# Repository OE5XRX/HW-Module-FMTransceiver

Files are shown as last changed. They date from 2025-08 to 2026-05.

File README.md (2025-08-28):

# HW-Module-Template

## Description

This repository is a template for hardware modules using KiCad, designed for clean, maintainable development with CI/CD pipelines generating and publishing production data automatically.

## Features
* Structured KiCad project (schematic, PCB)
* Clean repository: no production data stored
* GitHub Actions CI/CD pipeline:
  * Generates Gerber, BOM, and assembly files
  * Uploads artifacts to GitHub Releases
* Open Hardware license ready (CERN-OHL-S)

## Repository Structure

```
HW-Module-Template/
├── .github/workflows/     # CI/CD pipeline scripts
├── doc/                   # Documentation exports
├── symbols/               # Local symbol library (if needed)
├── footprints/            # Local footprint library (if needed)
├── 3d-models/             # STEP/WRL files (optional)
├── main.kicad_pro         # KiCad main project file
├── main.kicad_sch         # KiCad main schematic file
├── main.kicad_pcb         # KiCad main pcb file
├── *.kicad_sch            # other KiCad schematic files
├── LICENSE
└── README.md
```

## Usage
1. Click “Use this template” on GitHub.
2. Clone your repository locally and open in KiCad.
3. fix the missing names in the readme and add documentation in the `doc/index.md` file.
4. Work on your schematic and PCB as usual (create a new project (main-file must be called `main.kicad_*`) or copy a new one into the folder structure).
5. Push your changes.
6. CI/CD will automatically generate production files.
7. If there is a release defined, CI/CD will create a documentation on the main webpage.

## License

This project is licensed under [CERN-OHL-S-2.0](https://choosealicense.com/licenses/cern-ohl-s-2.0/).

## Badges

<br>
<br>
<br>
<br>
<br>

## Contact

OE5XRX Amateur Radio Club<br>
🌐 https://oe5xrx.org<br>
✉️ info@oe5xrx.org<br>

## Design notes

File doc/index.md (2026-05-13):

---
title: FM Transceiver
nav_order: 5
parent: Hardware
description: FM-Schmalband-Transceiver für 2 m (VHF) oder 70 cm (UHF) auf Basis SA818, mit STM32U5 als USB-Bridge — erscheint dem CM4 als USB-Audio-Class-2 + CDC-ACM-Verbund.
---

# FM Transceiver PCB

<table>
  <tr><th>Top</th><th>Bottom</th></tr>
  <tr>
    <td>top</td>
    <td>bottom</td>
  </tr>
</table>

## Übersicht

FM-Schmalband-Transceiver auf Basis des **SA818**-Moduls für die Amateurfunkbänder **2 m (144 – 174 MHz)** *oder* **70 cm (400 – 480 MHz)**. Bestückbar in beiden Varianten — abhängig vom verlöteten SA818-Chip (`SA818V` für VHF / `SA818U` für UHF) und dem dazu passenden Mini-Circuits-Tiefpassfilter (`LFCN-180` für VHF / `LFCN-490` für UHF; identischer FV1206-Footprint).

Zwischen SA818 und CM4 sitzt ein **STM32U575** Mikrocontroller. Er stellt sich am USB als **Composite Device** vor und sieht für das CM4-Linux aus wie:

- **UAC2** (USB Audio Class 2) — TX-Audio strömt vom CM4 als Audio-Sink in den STM32-DAC und von dort als analoges Signal zum SA818-Mic-Input. RX-Audio läuft umgekehrt: SA818-AF_OUT → STM32-ADC → über UAC2 als Audio-Source zurück ans CM4.
- **CDC ACM** (Virtual COM Port) — PTT, Squelch-Read, Frequenz, Power-Level usw. werden vom CM4 als ASCII-Kommandos über `/dev/ttyACM*` gesetzt.
- **DFU** (Device Firmware Upgrade) — STM32-Firmware kann über USB neu geflasht werden, ohne SWD-Adapter und ohne BOOT0-Hardware-Jumper.

Das Modul belegt einen der vier Slots auf dem [BusBoard](../HW-Module-BusBoard/). Die Kommunikation zum CM4 läuft **ausschließlich über USB** (USB-Pair am Bus-Stecker, durch den FE1.1s-Hub auf dem BusBoard); I²C, UART und GPIO-Pins des Bus-Steckers sind NICHT genutzt.

## Block-Diagramm

```mermaid
flowchart LR
    CM4["CM4<br/>(via BusBoard FE1.1s)"]
    CM4 <-->|"USB 2.0<br/>(UAC2 + CDC + DFU)"| ESD["USBLC6-2SC6<br/>ESD"]
    ESD <--> STM32["STM32U575CITx"]

    STM32 -->|"UART RX/TX<br/>AT-Kommandos"| SA["SA818V/U"]
    STM32 -->|"DAC (TX-Audio)"| MICF["DAC→MIC_IN<br/>Filter"]
    MICF --> SA
    SA -->|"AF_OUT (RX-Audio)"| AFF["AF_OUT→ADC<br/>Filter"]
    AFF -->|"ADC"| STM32
    STM32 -->|"GPIO1: PTT"| PDR["Pin-Driver<br/>(MOSFET/NPN)"]
    STM32 -->|"GPIO2: PD"| PDR
    STM32 -->|"GPIO3: H/L"| PDR
    PDR --> SA
    SA -->|"SQUELCH"| PDR
    PDR -->|"GPIO4"| STM32
    SA -->|"RF-Out"| LPF["LPF FL101<br/>(LFCN-180 = 2m,<br/>LFCN-490 = 70cm)"]
    LPF --> ANT(["Antenne<br/>SMA edge"])

    STM32 -.->|"I²C intern"| EEP["CAT24C32<br/>4 KByte EEPROM"]
```

## Band-Varianten

Die Platine ist für beide Amateurfunk-Bänder ausgelegt; bestückungsabhängig:

| Variante | SA818-Chip | LPF-Bestückung (FL101) | Band |
| --- | --- | --- | ---- |
| **2 m / VHF** | `SA818V` | `LFCN-180` | 144 – 174 MHz |
| **70 cm / UHF** | `SA818U` | `LFCN-490` | 400 – 480 MHz |

Es gibt nur **einen einzigen Filter-Footprint** (FL101 — Mini-Circuits FV1206) auf der Platine. Je nach SA818-Bestückung wird das passende LFCN-Bauteil eingelötet.

⚠️ **Wichtig**: SA818-Chip und LPF-Bestückung müssen zueinander passen. Ein falsch bestückter Filter unterdrückt entweder das Nutzband oder lässt zu viele Oberwellen durch → Empfangsperformance schlecht und/oder Verstoß gegen Spektrumvorschriften.

## Steckverbinder

| Bezeichner | Typ | Funktion |
| --- | --- | --- |
| **J101** | Board-Edge SMA | Antennenanschluss (50 Ω) |
| **J201** | 10-Pin 2.54 mm Stiftleiste 2×5 horizontal (right-angle) | STM32-Programming- und Debug-Header (SWD-Pin-Belegung) |
| **J202** | 20-Pin (Hirose **PCN10C-20S-2.54DS** — weibliche Buchse, paart mit dem PCN10-20P-Stift-Header auf dem BusBoard) | Bus-Stecker zum [BusBoard](../HW-Module-BusBoard/) |
| **JP201** | 2× Lötpad | EEPROM-Write-Protect-Brücke (siehe „EEPROM" unten) |

### Bus-Stecker J202 (FM-Slot-Sicht)

Das FM-Modul ist ein Device-Slot-Konsument. Power-Belegung identisch zu allen anderen Slots; nur USB ist aktiv, alle anderen Slot-Signal-Pins (`a7`–`a9`, `b7`–`b9`) sind NC.

| Pin | Net | Pin | Net |
|----:|-----|----:|-----|
| a1  | +12V | b1  | +12V |
| a2  | +12V | b2  | +12V |
| a3  | GND  | b3  | GND  |
| a4  | +5V  | b4  | +5V  |
| a5  | +5V  | b5  | +5V  |
| a6  | USB D+ | b6 | USB D− |
| a7  | NC | b7  | NC |
| a8  | NC | b8  | NC |
| a9  | NC | b9  | NC |
| a10 | GND  | b10 | GND  |

Hinweis: Pin-Numerierung am FM-Modul ist **gespiegelt** ggü. dem BusBoard-Slot (FM `a1` ↔ BusBoard `a10` usw.) — physikalisch passt's. Kanonische Bus-Pinbelegung siehe [BusBoard](../HW-Module-BusBoard/#pin-belegung-20-pin-identisch-auf-allen-konnektoren).

### STM32 SWD-Header J201

10-Pin 2.54-mm-Stiftleiste (2×5, right-angle/horizontal). Pin-Belegung folgt der SWD-Konvention, der Stecker selbst ist aber **kein** Cortex-Debug-1.27-mm-Standard — Adapter-Kabel für 2.54 mm benötigt, oder Jumper-Litzen direkt auf die einzelnen Pins.

| Pin | Signal | Pin | Signal |
|----:|---|----:|---|
| 1 | +3V3 | 2 | SWDIO |
| 3 | GND | 4 | SWCLK |
| 5 | GND | 6 | NC |
| 7 | NC | 8 | NC |
| 9 | GND | 10 | nRESET |

**Pin-1-Lage im Silkscreen ist auf der aktuellen Revision NICHT markiert** ([Issue #13](https://github.com/OE5XRX/HW-Module-FMTransceiver/issues/13)) — Schaltplan zur Hand nehmen oder die Pin-1-Markierung vom Programmer-Kabel mit einem Multimeter gegen `+3V3` verifizieren.

## STM32 ↔ SA818 — Steuersignal-Mapping

Die STM32-GPIOs steuern das SA818 über Level-Shifter (MOSFET / NPN — `pin_driver` und `pin_driver_npn` Sub-Sheets):

| Funktion | Schaltplan-Label | STM32-Pin (LQFP-48) | SA818-Pin | Richtung |
| --- | --- | --- | --- | --- |
| **PTT** (Push-to-Talk) | `GPIO1` | `PB2` (Pin 20) | `~PTT` (Pin 5) | STM32 → SA818 |
| **POWER_DOWN** (Modul ein/aus) | `GPIO2` | `PB1` (Pin 19) | `~PD` (Pin 6) | STM32 → SA818 |
| **H_L_Power** (Sendeleistung high/low) | `GPIO3` | `PB10` (Pin 21) | `H/L` (Pin 7) | STM32 → SA818 |
| **SQUELCH** (Squelch-Open-Indikator) | `GPIO4` | `PB0` (Pin 18) | `~SQ` (Pin 1) | SA818 → STM32 |

Zusätzlich UART auf STM32 USART_TX/USART_RX ↔ SA818 für AT-Kommandos (Frequenz setzen, Modulation, CTCSS, etc. — siehe SA818-Datenblatt).

## Firmware-Rolle (STM32U575)

Die STM32-Firmware (Quelle: [`FW-RemoteStation`](https://github.com/OE5XRX/FW-RemoteStation)) macht aus dem FM-Modul ein selbst beschreibendes USB-Gerät am CM4:

| USB-Klasse | Zweck | CM4-Sicht |
| --- | ----- | --- |
| **UAC2** | Audio-Class 2 für TX- und RX-Audio | Sound-Karte: aufnehmen vom Modul (RX-Audio) und abspielen zum Modul (TX-Audio) per ALSA/PipeWire. |
| **CDC ACM** | Kontroll-Pfad | `/dev/ttyACM*` — ASCII-Kommandos für PTT, Squelch-Read, Frequenz, Power-Level. |
| **DFU** | Firmware-Update | `dfu-util` kann die STM32-FW über USB neu schreiben — **kein BOOT0-Pin-Eingriff nötig**, die laufende Firmware switcht über CDC-Kommando in den DFU-Mode. |

Audio läuft vollständig analog zwischen SA818 und STM32 (DAC/ADC im STM32) — keine Echtzeit-Anforderungen am CM4-Linux nötig, Audio wird als regulärer USB-Audio-Stream behandelt.

## Auf der Platine verbaute Komponenten

| Bauteil | Funktion |
| --- | --- |
| **SA818V / SA818U** (U101) | FM-Schmalband-Transceiver-Modul (1 W TX-Leistung). Bestückung je nach Band. |
| **STM32U575CITx** (U201) | Cortex-M33 USB-Bridge. UAC2 + CDC + DFU Composite Device. |
| **TLV73333PQDBVRQ1** (U203) | Automotive-grade (-Q1) 3.3 V LDO — Versorgung für STM32 + Peripherie. |
| **USBLC6-2SC6** (U204) | USB-ESD-Schutz auf den D±-Leitungen vor STM32. |
| **CAT24C32** (U202) | 32 Kbit (4 KByte) I²C EEPROM. WP-Pin über `JP201`-Lötbrücke konfigurierbar. |
| **LMR51430** (U801) | Buck-Konverter 12 V → 5 V für die SA818-Versorgung. |
| **LFCN-180** *oder* **LFCN-490** (FL101) | Mini-Circuits Tiefpass im Antennen-Pfad (Oberwellen-Unterdrückung). Eines der beiden wird in den FV1206-Footprint bestückt — `LFCN-180` für 2 m, `LFCN-490` für 70 cm. |
| **8 MHz Crystal** | Taktquelle für den STM32U575 (Backup zum HSI). |
| **Pin Driver** (pin_driver / pin_driver_npn Sub-Sheets) | MOSFET- und NPN-Level-Shifter zwischen STM32-3.3-V-GPIOs und SA818. |

## EEPROM (CAT24C32)

4-KByte-EEPROM am internen I²C-Bus des STM32 (separate I²C-Lines `I2C_SCL_MEM`/`I2C_SDA_MEM` von Pin 45/46 — also nicht über den Bus zum CM4 erreichbar). **Vorgesehen für Modul-Konfiguration** (Seriennummer, Kalibrierdaten, gespeicherte Frequenzlisten o.ä.). **Aktuell noch leer** — Firmware definiert das Schema noch.

**Write-Protect** über `JP201` (zwei Lötpads, KEIN Pin-Header):

| JP201 | Verhalten |
| ----- | --- |
| **offen** (Default ab JLCPCB) | EEPROM beschreibbar — STM32 kann CAT24C32 lesen UND schreiben. |
| **gebrückt** (Lötzinn-Brücke) | EEPROM schreibgeschützt (CAT24C32 Pin 7 / WP = high). Nur Lesen möglich. |

In der Endmontage (Produktivbetrieb) ist es empfehlenswert die Brücke zu setzen, damit kein Firmware-Bug versehentlich Kalibrierdaten überschreibt.

## Versorgung

| Rail | Quelle | Verbrauch |
| ---- | --- | --- |
| +12V | Bus-Stecker (vom [PowerBoard](../HW-Module-PowerBoard/)) | < 1 A (SA818 TX-Spitze) |
| +5V  | Lokaler LMR51430 Buck aus +12V | für SA818 |
| +3V3 | Lokaler TLV73333-Q1 LDO aus +5V | für STM32, EEPROM, Pin-Driver-Logik |

Hinweis: das Modul nutzt sowohl die +12V- *als auch* die +5V-Schiene vom Bus — die +5V vom Bus speist die USB-Interface-Schaltung (USBLC6), während die SA818-Versorgung lokal aus den +12V gezogen wird (saubere Trennung von Audio/Digital und HF/Switching-Noise).

## Bestückung

- **SA818** und passender **LFCN-Filter** müssen zusammenpassen — siehe Band-Varianten-Tabelle oben. Bei JLCPCB-Order entsprechende Variant-Auswahl im KiBot-Setup.
- **`JP201`-Lötbrücke** wird ab Werk **offen** geliefert (EEPROM beschreibbar zur Initialkonfiguration). Brücke kann nach Konfiguration mit Lötzinn geschlossen werden.
- Antenne: **Niemals senden ohne Antenne oder 50-Ω-Dummy-Last** am SMA — das SA818 verträgt offene/kurzgeschlossene Antennen-Ports nicht und kann beschädigt werden.

## Bringup

Nach Bestückung (mit Bus + CM4 verbunden):

1. **Power-Sanity:** Modul in Slot stecken, +12 V anlegen, am Bus-Stecker `+5V`-Pin gegen GND messen → 5.00 ± 0.05 V (LMR51430-Output). `+3V3` (z.B. am SWD-Header J201 Pin 1 vs Pin 3) muss 3.30 ± 0.05 V zeigen.
2. **STM32-Boot:** kurze Latenz nach Power-Up sollte am USB ein Composite Device erscheinen (`lsusb -v` am CM4). Drei USB-Interfaces sind erwartet: UAC2 (Audio), CDC ACM (Serial), DFU-Runtime.
3. **Soundkarten-Check:** `aplay -L` / `arecord -L` am CM4 → die FM-Module-UAC2-Soundkarte muss in der Liste sein.
4. **CDC-Konsole:** `screen /dev/ttyACM0 115200` (oder welche Nummer auch immer) — Firmware-spezifisches Prompt/Echo erwartet.
5. **SA818-Smoke:** über CDC-Kommando Frequenz setzen, dann mit Funkscanner / SDR auf der eingestellten Frequenz Trägeraussendung kurz testen (5-Sek-Burst max, **mit Antenne!**).
6. **Firmware-Update-Pfad:** über CDC-Kommando in DFU schalten, mit `dfu-util -l` muss das Modul auftauchen — bestätigt dass auch Firmware-Updates über reines USB möglich sind, ohne SWD-Programmer.

## Verwandte Module

- [BusBoard](../HW-Module-BusBoard/) — stellt USB-Anbindung über FE1.1s-Hub bereit.
- [PowerBoard](../HW-Module-PowerBoard/) — speist +12 V / +5 V am Bus.
- [CM4 Carrier](../HW-Module-CM4Carrier/) — USB-Host und Software-Endpoint für UAC2/CDC/DFU.
- [`FW-RemoteStation`](https://github.com/OE5XRX/FW-RemoteStation) — STM32-Firmware-Quellcode.

## Daten

- [Schaltplan]({{ site.data.project.name }}-schematic.pdf)
- [BOM]({{ site.data.project.name }}-bom.html)
- [iBOM]({{ site.data.project.name }}-ibom.html)
- [JLCPCB fabrication & stencil](JLCPCB/{{ site.data.project.name }}-_JLCPCB_compress.zip)
- [JLCPCB Bom](JLCPCB/{{ site.data.project.name }}_bom_jlc.csv)
- [JLCPCB Pick&Place](JLCPCB/{{ site.data.project.name }}_cpl_jlc.csv)

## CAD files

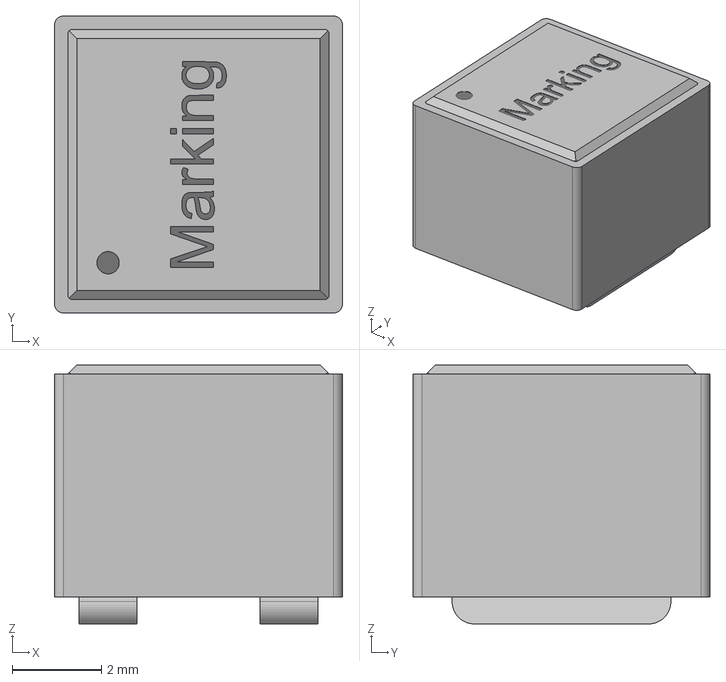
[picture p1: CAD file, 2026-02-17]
3d-models/WE-XHMI-6060.step
6.45 x 6.65 x 5.80 mm

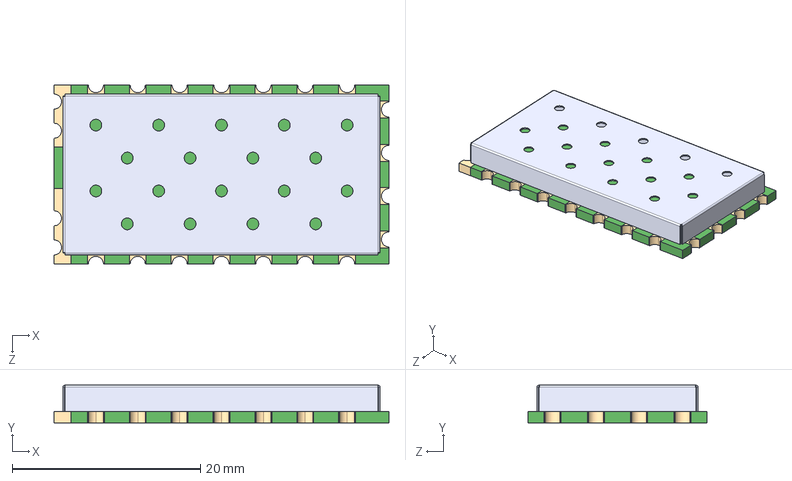
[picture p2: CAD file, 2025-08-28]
3d-models/DRA818.step
35.6 x 4.00 x 19.0 mm

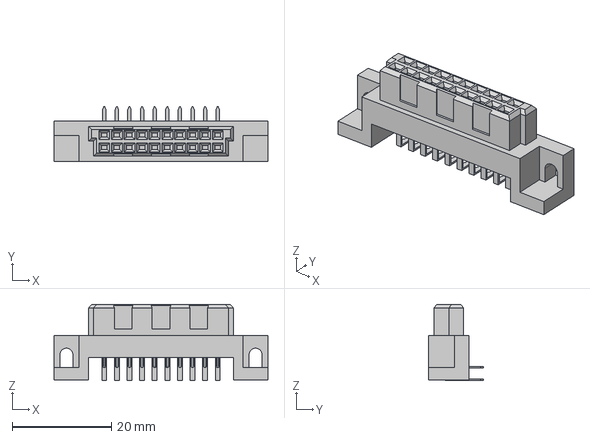
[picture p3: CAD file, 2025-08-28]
3d-models/PCN10C-20S-2.54DS.stp
43.1 x 11.0 x 15.3 mm

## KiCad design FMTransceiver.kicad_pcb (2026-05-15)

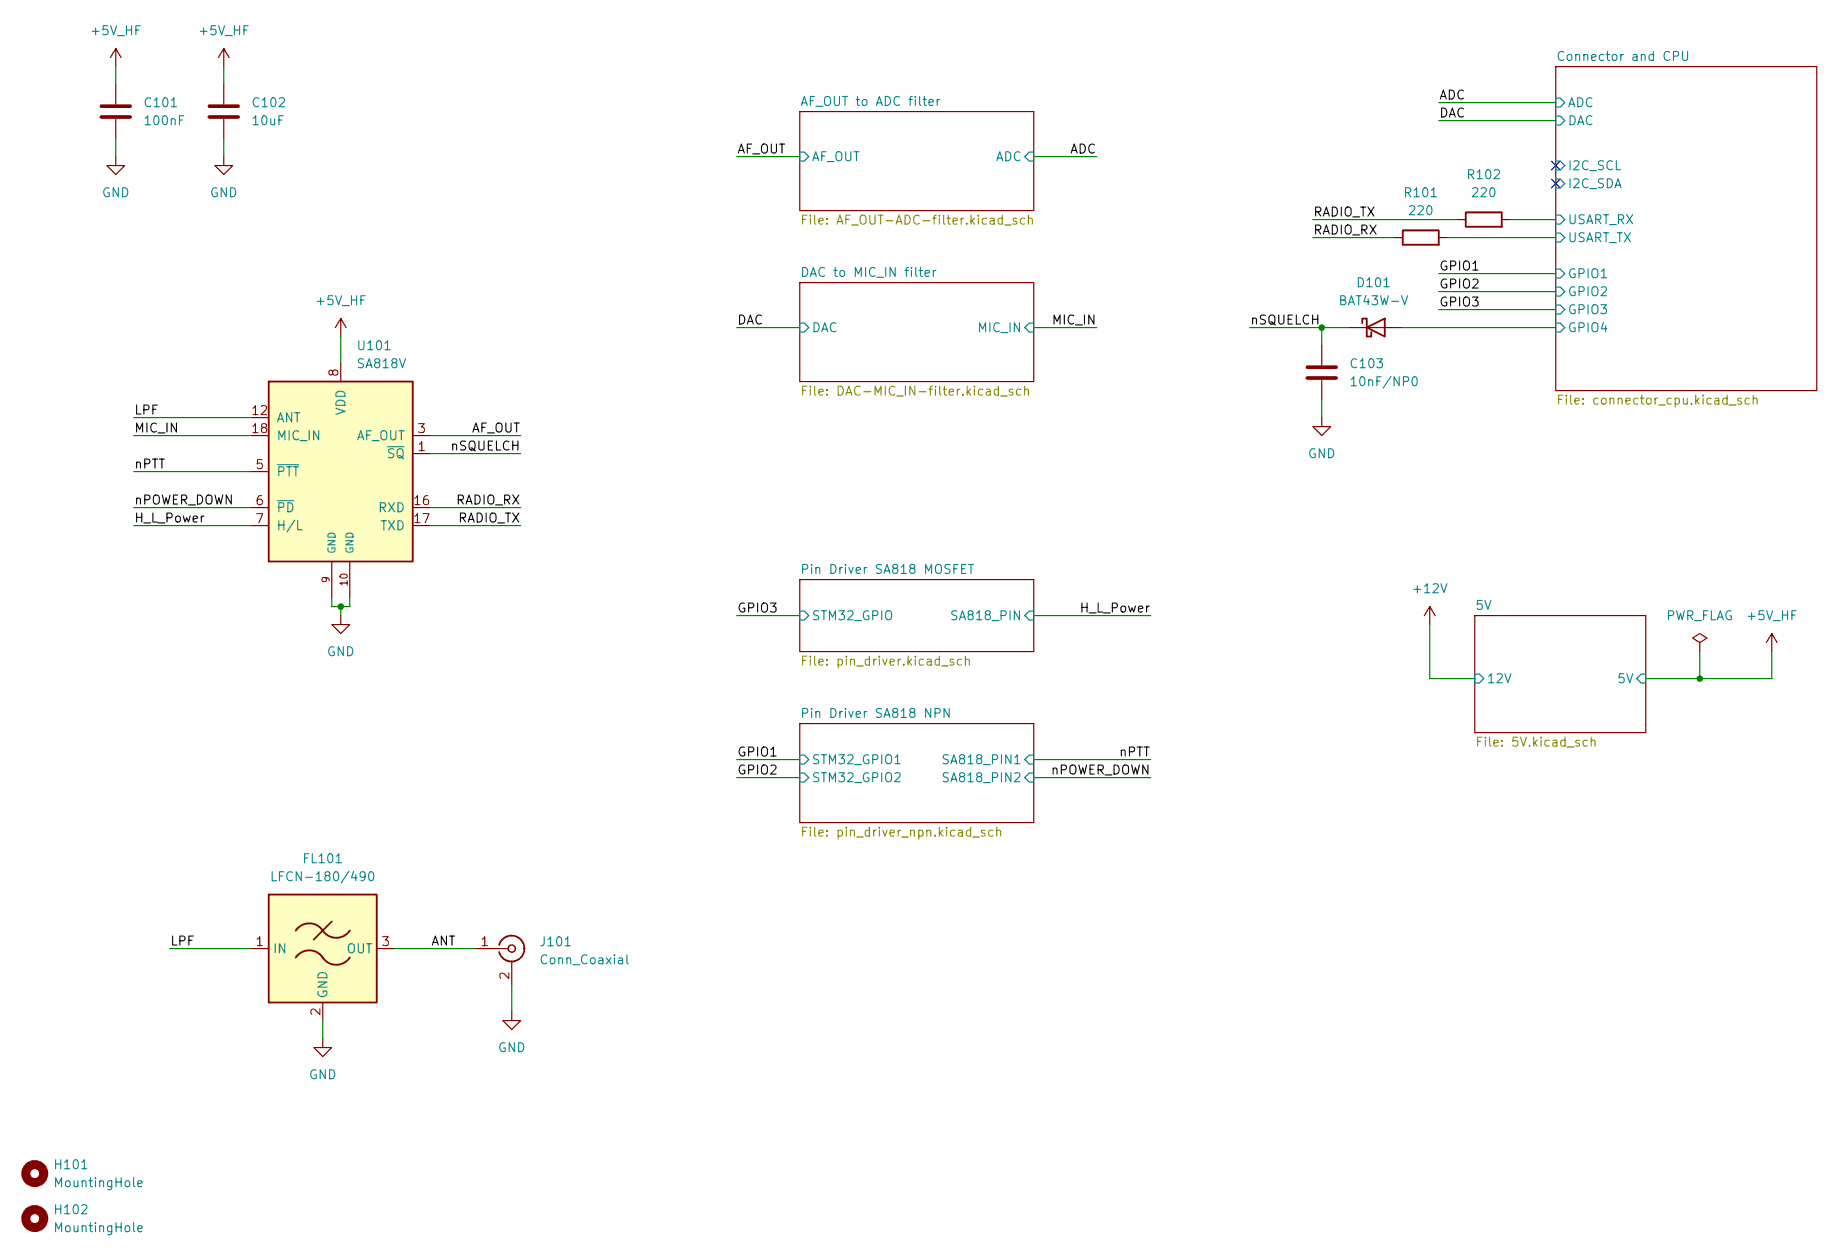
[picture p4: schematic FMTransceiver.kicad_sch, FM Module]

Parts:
C101: 100nF; C_0805_2012Metric; LCSC C28233
C102: 10uF; C_0805_2012Metric; MOUSER 963-EMK212BJ106KG-T
C103: 10nF/NP0; C_0805_2012Metric; MOUSER 81-GRM2165C2A103JA1D
D101: BAT43W-V; D_SOD-123; MOUSER 78-BAT43W-G3-08
FL101: LFCN-180/490; Filter_Mini-Circuits_FV1206; MOUSER 139-LFCN-180,139-LFCN-490
H101, H102: MountingHole; MountingHole_3.2mm_M3
J101: Conn_Coaxial; SMA_Amphenol_132289_EdgeMount; MOUSER 530-142-0701-801
R101, R102: 220; R_0805_2012Metric; MOUSER 667-ERA-6AEB221V
U101: SA818V; DRA818; LCSC C3001504

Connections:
+5V_HF: C101.2, C102.2, U101.8 (VDD); also elsewhere on the board
/AF_OUT: U101.3 (AF_OUT); also elsewhere on the board
/ANT: FL101.3 (OUT), J101.1 (In)
/Connector and CPU/GPIO4: D101.2 (A); also elsewhere on the board
/Connector and CPU/USART_RX: R102.2; also elsewhere on the board
/Connector and CPU/USART_TX: R101.2; also elsewhere on the board
/H_L_Power: U101.7 (H/L); also elsewhere on the board
/LPF: FL101.1 (IN), U101.12 (ANT)
/MIC_IN: U101.18 (MIC_IN); also elsewhere on the board
/RADIO_RX: R101.1, U101.16 (RXD)
/RADIO_TX: R102.1, U101.17 (TXD)
/nPOWER_DOWN: U101.6 (~PD); also elsewhere on the board
/nPTT: U101.5 (~PTT); also elsewhere on the board
/nSQUELCH: C103.2, D101.1 (K), U101.1 (~SQ)
GND: C101.1, C102.1, C103.1, FL101.2 (GND), FL101.4 (GND), J101.2 (Ext), U101.9 (GND), U101.10 (GND); also elsewhere on the board

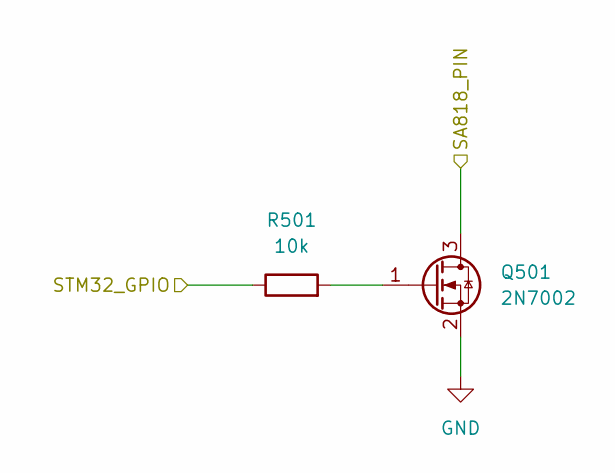
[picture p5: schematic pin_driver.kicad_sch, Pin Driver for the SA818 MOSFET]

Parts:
Q501: 2N7002; SOT-23; MOUSER 637-2N7002
R501: 10k; R_0805_2012Metric; MOUSER 603-RT0805DRE0710KL

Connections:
/GPIO3: R501.1; also elsewhere on the board
/H_L_Power: Q501.3 (D); also elsewhere on the board
GND: Q501.2 (S); also elsewhere on the board
unnamed: Q501.1 (G), R501.2

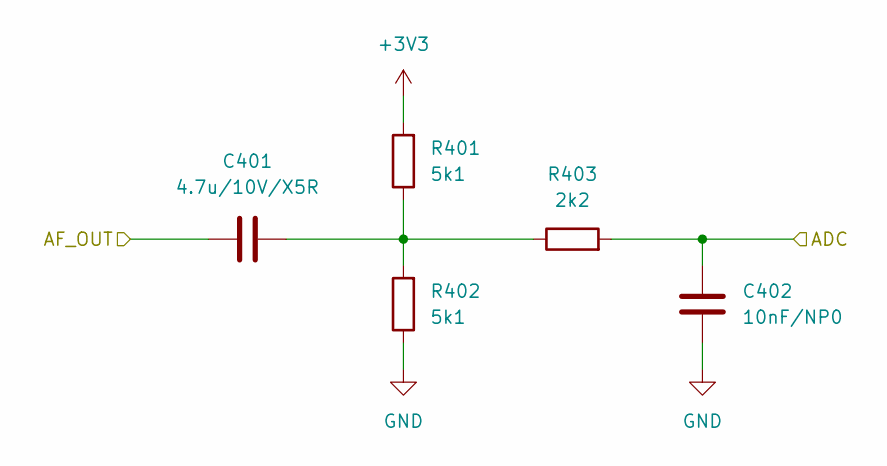
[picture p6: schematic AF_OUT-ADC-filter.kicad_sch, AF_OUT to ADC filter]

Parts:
C401: 4.7u/10V/X5R; C_0805_2012Metric; MOUSER 187-CL21A475KAQNNNF
C402: 10nF/NP0; C_0805_2012Metric; MOUSER 81-GRM2165C2A103JA1D
R401, R402: 5k1; R_0805_2012Metric; LCSC C27834
R403: 2k2; R_0805_2012Metric; LCSC C17520

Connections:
+3V3: R401.2; also elsewhere on the board
/ADC: C402.2, R403.2; also elsewhere on the board
/AF_OUT: C401.2; also elsewhere on the board
GND: C402.1, R402.1; also elsewhere on the board
unnamed: C401.1, R401.1, R402.2, R403.1

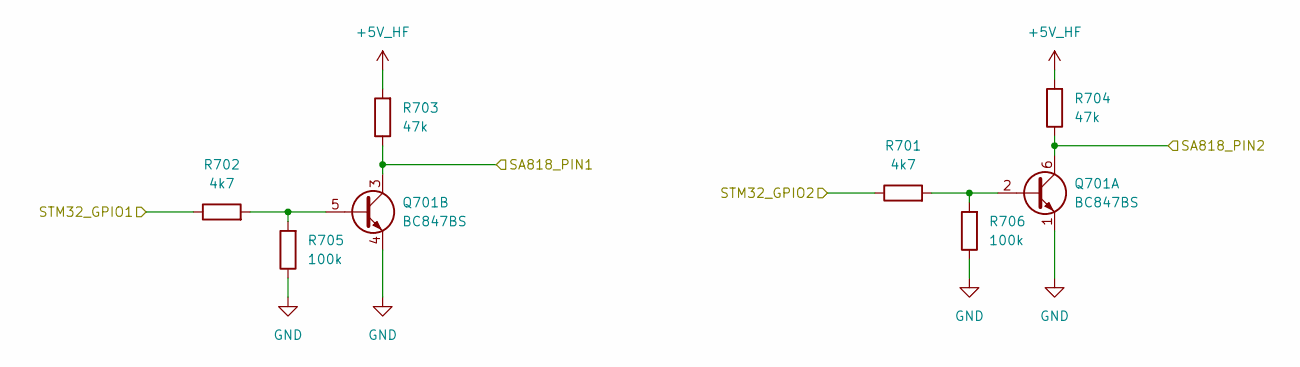
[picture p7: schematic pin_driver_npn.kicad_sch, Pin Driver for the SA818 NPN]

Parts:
Q701: BC847BS; SOT-363_SC-70-6; MOUSER 241-BC847BS_R1_00001
R701, R702: 4k7; R_0805_2012Metric; MOUSER 603-RC0805FR-074K7L
R703, R704: 47k; R_0805_2012Metric; MOUSER 603-AC0805FR-1047KL
R705, R706: 100k; R_0805_2012Metric; MOUSER 603-RC0805JR-07100KL

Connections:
+5V_HF: R703.2, R704.2; also elsewhere on the board
/GPIO1: R702.1; also elsewhere on the board
/GPIO2: R701.1; also elsewhere on the board
/nPOWER_DOWN: Q701.6 (C1), R704.1; also elsewhere on the board
/nPTT: Q701.3 (C2), R703.1; also elsewhere on the board
GND: Q701.1 (E1), Q701.4 (E2), R705.1, R706.1; also elsewhere on the board
unnamed: Q701.2 (B1), R701.2, R706.2
unnamed: Q701.5 (B2), R702.2, R705.2

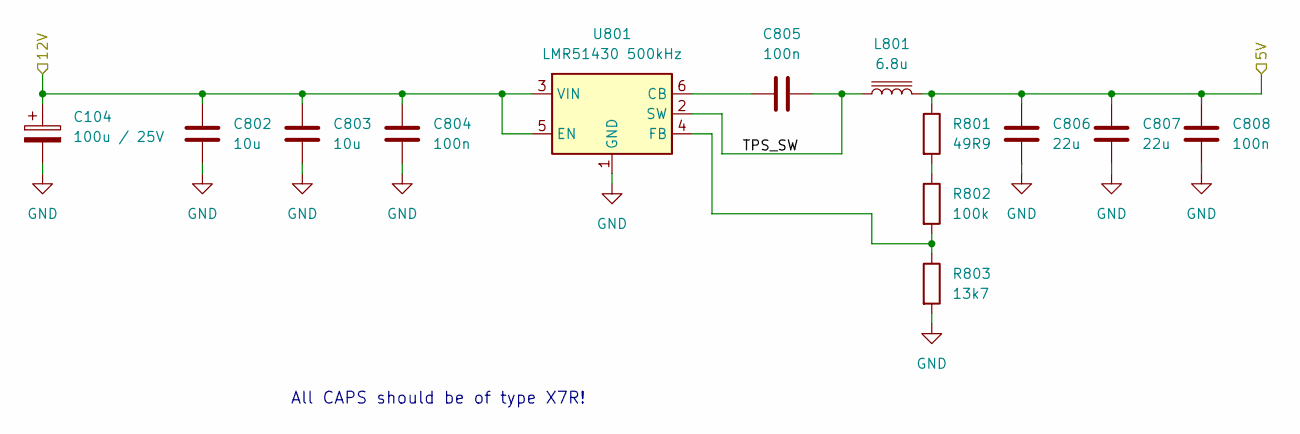
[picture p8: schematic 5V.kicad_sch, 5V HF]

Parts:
C104: 100u / 25V; CP_EIA-7343-43_Kemet-X; LCSC C132558
C802, C803: 10u; C_1206_3216Metric; LCSC C13585
C804, C805, C808: 100n; C_0805_2012Metric; LCSC C28233
C806, C807: 22u; C_1206_3216Metric; LCSC C12891
L801: 6.8u; WE-XHMI_6060; MOUSER 710-74439346068
R801: 49R9; R_0805_2012Metric; MOUSER 667-ERA-6AED49R9V
R802: 100k; R_0805_2012Metric; MOUSER 603-RC0805JR-07100KL
R803: 13k7; R_0805_2012Metric; MOUSER 652-CR0805FX-1372ELF
U801: LMR51430 500kHz; SOT-23-6; MOUSER 595-LMR51430XDDCR

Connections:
+5V_HF: C806.2, C807.2, C808.2, L801.2, R801.1; also elsewhere on the board
+12V: C104.1, C802.1, C803.1, C804.1, U801.3 (VIN), U801.5 (EN); also elsewhere on the board
/5V/TPS_SW: C805.2, L801.1, U801.2 (SW)
GND: C104.2, C802.2, C803.2, C804.2, C806.1, C807.1, C808.1, R803.2, U801.1 (GND); also elsewhere on the board
unnamed: R801.2, R802.1
unnamed: C805.1, U801.6 (CB)
unnamed: R802.2, R803.1, U801.4 (FB)

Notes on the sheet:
All CAPS should be of type X7R!

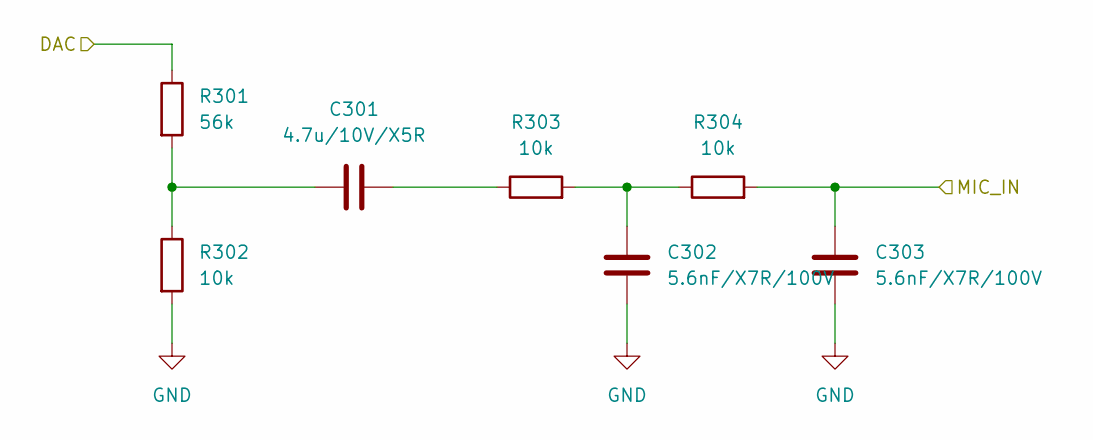
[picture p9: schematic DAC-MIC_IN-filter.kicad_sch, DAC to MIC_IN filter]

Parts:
C301: 4.7u/10V/X5R; C_0805_2012Metric; MOUSER 187-CL21A475KAQNNNF
C302, C303: 5.6nF/X7R/100V; C_0805_2012Metric; MOUSER 791-0805B562K201CT
R301: 56k; R_0805_2012Metric; MOUSER 603-RT0805DRE0756KL
R302, R303, R304: 10k; R_0805_2012Metric; MOUSER 603-RT0805DRE0710KL

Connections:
/DAC: R301.1; also elsewhere on the board
/MIC_IN: C303.1, R304.2; also elsewhere on the board
GND: C302.2, C303.2, R302.2; also elsewhere on the board
unnamed: C301.1, R303.1
unnamed: C301.2, R301.2, R302.1
unnamed: C302.1, R303.2, R304.1

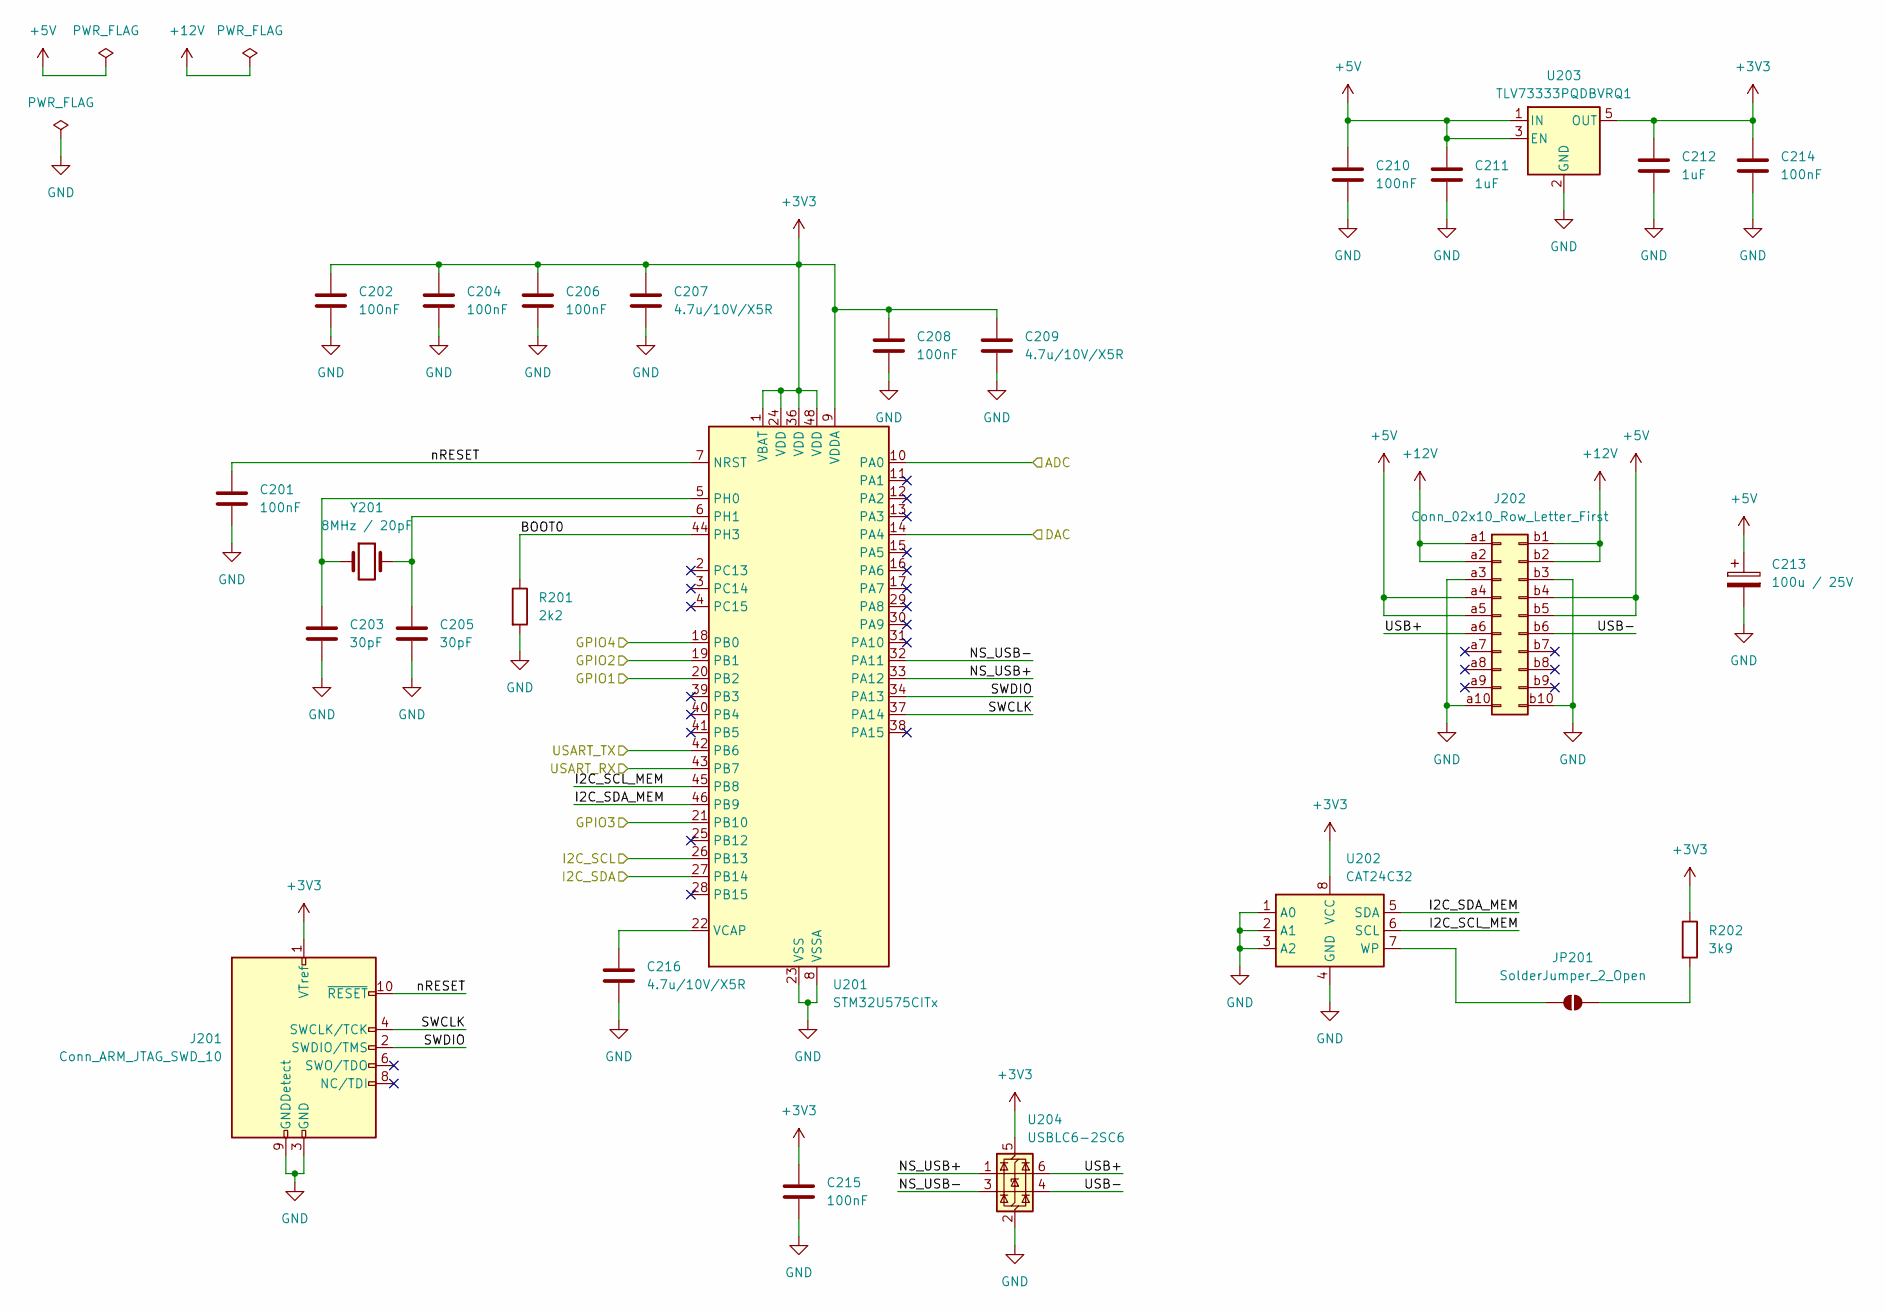
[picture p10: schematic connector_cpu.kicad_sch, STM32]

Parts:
C201, C202, C204, C206, C208, C210, C214, C215: 100nF; C_0805_2012Metric; LCSC C28233
C203, C205: 30pF; C_0805_2012Metric; MOUSER 791-0805N300J500CT
C207, C209, C216: 4.7u/10V/X5R; C_0805_2012Metric; MOUSER 187-CL21A475KAQNNNF
C211, C212: 1uF; C_0805_2012Metric; MOUSER 791-0805B105K250CT
C213: 100u / 25V; CP_EIA-7343-43_Kemet-X; LCSC C132558
J201: Conn_ARM_JTAG_SWD_10; PinHeader_2x05_P2.54mm_Horizontal
J202: Conn_02x10_Row_Letter_First; PCN10C-20S-2.54DS; MOUSER 798-PCN10C20S254DS72
JP201: SolderJumper_2_Open; SolderJumper-2_P1.3mm_Open_RoundedPad1.0x1.5mm
R201: 2k2; R_0805_2012Metric; LCSC C17520
R202: 3k9; R_0805_2012Metric; MOUSER 603-RT0805DRD073K9L
U201: STM32U575CITx; LQFP-48_7x7mm_P0.5mm; MOUSER 511-STM32U575CIT6
U202: CAT24C32; SOIC-8_3.9x4.9mm_P1.27mm; MOUSER 698-CAT24C32WI-GT3
U203: TLV73333PQDBVRQ1; SOT-23-5; LCSC C2862550
U204: USBLC6-2SC6; SOT-23-6; LCSC C2827654
Y201: 8MHz / 20pF; Crystal_SMD_HC49-SD; MOUSER 73-XT49M800-20

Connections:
+3V3: C202.2, C204.2, C206.2, C207.2, C208.2, C209.2, C212.1, C214.2, C215.1, J201.1 (VTref), R202.1, U201.1 (VBAT), U201.9 (VDDA), U201.24 (VDD), U201.36 (VDD), U201.48 (VDD), U202.8 (VCC), U203.5 (OUT), U204.5 (VBUS); also elsewhere on the board
+5V: C210.2, C211.1, C213.1, J202.a4, J202.a5, J202.b4, J202.b5, U203.1 (IN), U203.3 (EN)
+12V: J202.a1, J202.a2, J202.b1, J202.b2; also elsewhere on the board
/ADC: U201.10 (PA0); also elsewhere on the board
/Connector and CPU/BOOT0: R201.1, U201.44 (PH3)
/Connector and CPU/GPIO4: U201.18 (PB0); also elsewhere on the board
/Connector and CPU/I2C_SCL: U201.26 (PB13)
/Connector and CPU/I2C_SCL_MEM: U201.45 (PB8), U202.6 (SCL)
/Connector and CPU/I2C_SDA: U201.27 (PB14)
/Connector and CPU/I2C_SDA_MEM: U201.46 (PB9), U202.5 (SDA)
/Connector and CPU/NS_USB+: U201.33 (PA12), U204.1 (I/O1)
/Connector and CPU/NS_USB-: U201.32 (PA11), U204.3 (I/O2)
/Connector and CPU/SWCLK: J201.4 (SWCLK/TCK), U201.37 (PA14)
/Connector and CPU/SWDIO: J201.2 (SWDIO/TMS), U201.34 (PA13)
/Connector and CPU/USART_RX: U201.43 (PB7); also elsewhere on the board
/Connector and CPU/USART_TX: U201.42 (PB6); also elsewhere on the board
/Connector and CPU/USB+: J202.a6, U204.6 (I/O1)
/Connector and CPU/USB-: J202.b6, U204.4 (I/O2)
/Connector and CPU/nRESET: C201.1, J201.10 (~RESET), U201.7 (NRST)
/DAC: U201.14 (PA4); also elsewhere on the board
/GPIO1: U201.20 (PB2); also elsewhere on the board
/GPIO2: U201.19 (PB1); also elsewhere on the board
/GPIO3: U201.21 (PB10); also elsewhere on the board
GND: C201.2, C202.1, C203.2, C204.1, C205.2, C206.1, C207.1, C208.1, C209.1, C210.1, C211.2, C212.2, C213.2, C214.1, C215.2, C216.1, J201.3 (GND), J201.5 (GND), J201.9 (GNDDetect), J202.a3, J202.a10, J202.b3, J202.b10, R201.2, U201.8 (VSSA), U201.23 (VSS), U201.35 (VSS), U201.47 (VSS), U202.1 (A0), U202.2 (A1), U202.3 (A2), U202.4 (GND), U203.2 (GND), U204.2 (GND); also elsewhere on the board
unnamed: JP201.1 (A), U202.7 (WP)
unnamed: JP201.2 (B), R202.2
unnamed: C203.1, U201.5 (PH0), Y201.1
unnamed: C205.1, U201.6 (PH1), Y201.2
unnamed: C216.2, U201.22 (VCAP)

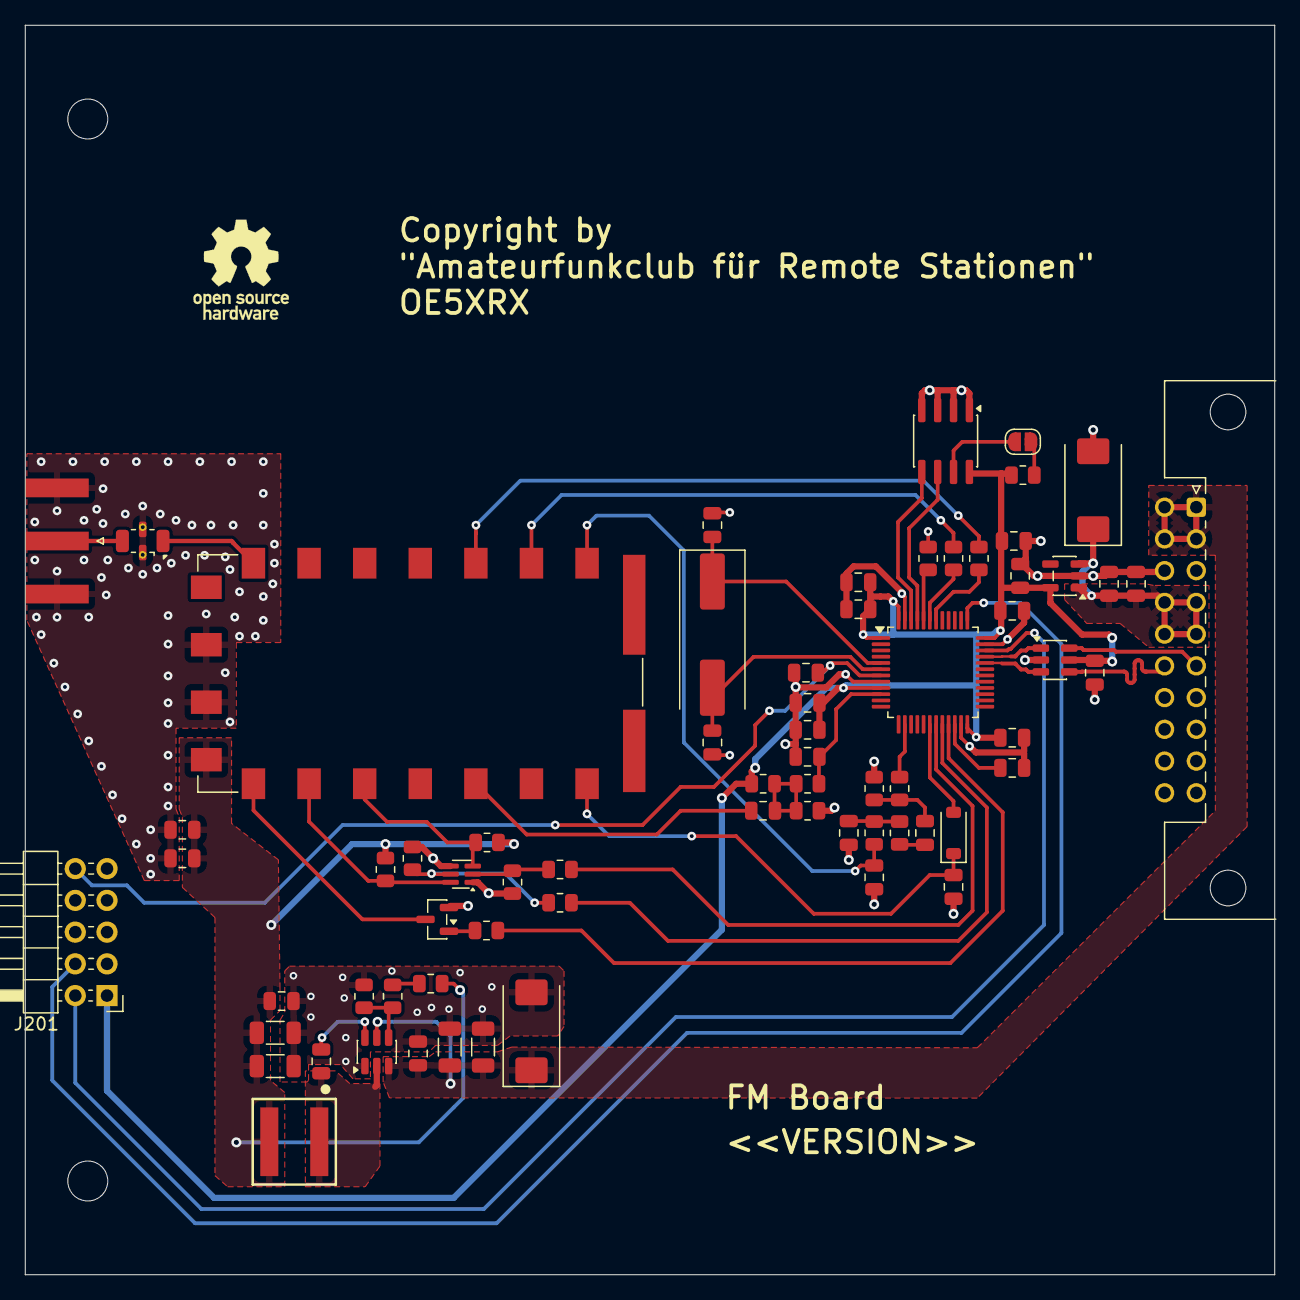
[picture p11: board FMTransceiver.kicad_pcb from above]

Board: 4 copper layers, 100.0 x 100.0 mm, 71 parts (0 on the bottom side), 49 nets.

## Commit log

2025-08-28 setup project
    [5V.kicad_sch, AF_OUT-ADC-filter.kicad_sch, DAC-MIC_IN-filter.kicad_sch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]
2026-02-17 update stm32, add some new 3d files
    [WE-XHMI-6060.step, connector_cpu.kicad_sch, main.kicad_pcb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]
2026-02-17 fix pcb gnd
    [main.kicad_pcb]
2026-02-17 add mouser part numbers
    [5V.kicad_sch, AF_OUT-ADC-filter.kicad_sch, DAC-MIC_IN-filter.kicad_sch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]
2026-02-20 fix: remove hardcoded supplier PKs; warn on unknown KiCad symbols in category map
2026-05-11 Fix transistor symbol visibility and update polyline coordinates in schematic
    [connector_cpu.kicad_sch, main.kicad_pcb, pin_driver.kicad_sch]
2026-05-11 kicad update to 9.0.8
    [5V.kicad_sch, AF_OUT-ADC-filter.kicad_sch, DAC-MIC_IN-filter.kicad_sch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]
2026-05-11 rename(kicad): main.kicad_* -> FMTransceiver.kicad_*
    Distinguishable KiCad window titles on the desktop. The composite action
    in HW-Module-CI auto-detects the project name from the basename of
    *.kicad_pro, so CI behaviour is identical before and after — only the
    artefact filenames change (main-bom.html -> FMTransceiver-bom.html etc.),
    which doc/index.md already routes through {{ site.data.project.name }}.
    Internal references updated:
    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
    [5V.kicad_sch, AF_OUT-ADC-filter.kicad_sch, DAC-MIC_IN-filter.kicad_sch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]
2026-05-13 docs: rewrite FM Transceiver index.md with full architecture overview
    Adds:
    - 1-sentence description front-matter (band-agnostic — 2 m or 70 cm)
    - Übersicht clarifying USB-only CM4 communication via STM32U575
    Composite Device (UAC2 + CDC ACM + DFU)
    - Mermaid block diagram of the signal flow STM32 ↔ SA818 ↔ antenna
    - Band-variant table (SA818V + LFCN-160 for 2 m; SA818U + LFCN-180+490
    for 70 cm) with warning about chip/filter pairing
    - Steckverbinder table (J101 SMA, J201 SWD, J202 bus, JP201 solder-pad)
    - Bus pinout J202 (FM slot's local view — mirrored vs BusBoard slot)
    - SWD header pinout (J201) + TBD note linking to issue #13 for pin-1
    silkscreen marking
    - STM32 ↔ SA818 s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
2026-05-13 fix(docs): correct LPF filter spec — single FV1206 footprint (FL101), LFCN-180 for 2m / LFCN-490 for 70cm
    User correction:
    - 2m needs LFCN-180 (not LFCN-160 as I had — LFCN-160 doesn't even exist)
    - 70cm needs LFCN-490
    - Only ONE filter footprint on the board (FL101, FV1206) — not two
    The 'LFCN-160' value string I'd seen in the schematic only appears as a
    stale Value-property on the SA818 lib_symbol entry (copy-paste leftover
    in the symbol library), not on an actually-placed component. The real
    placed filter (FL101) has Value 'LFCN-180/490' on the FV1206 footprint
    and is alternately populated with LFCN-180 or LFCN-490 depending on band.
2026-05-13 docs(fm): address Copilot review findings
    7 issues from Copilot's review on PR #14, all valid after schematic
    + PCB verification:
    1. J201 (SWD-Header): 2.54 mm 2x5 horizontal pin header per PCB
    footprint Connector_PinHeader_2.54mm:PinHeader_2x05_P2.54mm_Horizontal,
    NOT 1.27 mm ARM-Cortex-Debug. Need 2.54 mm SWD adapter or per-pin
    jumper wires.
    2. J202 (Bus-Stecker): PRJ:PCN10C-20S-2.54DS per PCB — the female
    socket variant. Mates with the male PCN10-20P-2.54DSA pin header
    that's on the BusBoard. My doc had copy-pasted the BusBoard's
    male part number, which was wrong for the FM consumer side.
    3. STM32 ↔ SA818 GPIO mapping: user's quick-quoted PB values were
    wrong.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
2026-05-15 chore: migrate <<HASH>> placeholder to <<VERSION>> (#15)
    Aligns the KiCad title-block placeholder with the new versioning concept
    documented at oe5xrx.org/docs/remote-station/hardware/versioning/.
    The placeholder is substituted at CI time:
    - Release build: v1.5 → "1.5" (semver only, no `v`, no SHA)
    - Debug build: "BETA-<short-commit>"
    No electrical or layout change — pure text replacement on the title-block
    silkscreen text. Requires HW-Module-CI feat/version-placeholder
    (OE5XRX/HW-Module-CI#4) to be merged first; otherwise CI substitutes
    the old <<HASH>> token and leaves the new <<VERSION>> string literal
    in the title block until the CI side catches up.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
    [5V.kicad_sch, AF_OUT-ADC-filter.kicad_sch, DAC-MIC_IN-filter.kicad_sch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]
2026-08-30 ci: rebuild docs with new KiBot BOM logo (brand)

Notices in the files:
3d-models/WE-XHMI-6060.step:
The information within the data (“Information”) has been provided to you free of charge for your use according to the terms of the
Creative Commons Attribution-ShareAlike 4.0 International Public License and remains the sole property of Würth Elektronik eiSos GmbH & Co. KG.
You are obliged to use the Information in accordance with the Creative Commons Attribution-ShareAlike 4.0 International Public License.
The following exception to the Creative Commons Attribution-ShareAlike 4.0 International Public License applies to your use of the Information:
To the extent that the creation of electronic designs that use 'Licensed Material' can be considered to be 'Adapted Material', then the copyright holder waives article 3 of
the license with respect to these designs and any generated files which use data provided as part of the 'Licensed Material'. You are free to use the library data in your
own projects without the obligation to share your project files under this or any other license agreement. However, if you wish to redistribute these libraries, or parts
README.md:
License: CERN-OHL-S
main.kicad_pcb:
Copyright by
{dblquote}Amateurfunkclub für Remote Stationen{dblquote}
